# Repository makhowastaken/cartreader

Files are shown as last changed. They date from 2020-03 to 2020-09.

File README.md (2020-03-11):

# cartreader (name pending)

Apologies in advance, this repo is really all over the place. I'm trying to organize and document as I go and it's honestly taken more work to clean this project up and organize it than it has to actually create it in the first place. Things *will* be renamed eventually. 

This device was created from the schematic of [sanni's cart reader](https://github.com/sanni/cartreader) and even uses the same, unmodified firmware. Please see that repo for firmware and firmware updates. This device consists of two parts, the control unit which features the arduino itself, the peripherals, and the power supply, and then the interface adapter, which is largely just a passive adapter to allow you to insert whatever cart. Currently, feature parity has not been reached as I have yet to implement a N64 or Megadrive/Genesis adapter. 

cartreader

## control unit ("sanni_pro")

The Brians of the device. This uses the aftermarket ATMEGA2560 "Pro" boards for a smaller footprint. The actual hardware is largely unchanged from the original Arduino Pros but the footprint is massively reduced. 

This part is designed to be "self contained" and will include all the hardware necessary to operate the device in a portable manner. You need one or more of the following adapters still. 

[Click here for more info, PCB files, and assembly instructions/information of the control unit.](PCB%20Files/control%20unit)

## gb/c and gba adapter ("sanni_gba")

This is the primary adapter that I made this whole module for. I really liked my original reader but I wanted something smaller. This module may actually be combined with any of the other modules by sandwiching the other module inbetween this board and the control unit module.  

[Click here for more info, PCB files, and assembly instructions/information of the GBA adapter.](PCB%20Files/adapters/sanni_gba_shield)

## 8 bit flash module adapter adapter ("sanni_flash")

This is equivalent to the module that plugs into the SNES/SFC slot on sanni's reader that allows you to directly interface with flash chips. It is working (finally) and should interface with the same modules as sanni's version. Only the TSOP48 adapter is tested and confirmed working. I don't have flash chips to test the other adapters. 

[Click here for more info, PCB files, and assembly instructions/information of the flash adapter.](PCB%20Files/adapters/sanni_flash_shield)

## snes / sfc adapter ("sanni_snes")

This adapter is a work in progress. I have uploaded the current version that I have tested and confirmed works (except for the untested CIC lock circuit but it should be fine). Confirmed dumping of SFC games and functionality with sanni's addon modules that interface with the SNES/SFC slot. 

[Click here for more info, PCB files, and assembly instructions/information of the SFC adapter.](PCB%20Files/adapters/sanni_snes_shield)

## n64 adapter

todo

## md/genesis adapter

todo

## other adapters

Sanni's NES/FC adapters, Wonderswan adapter, and SMS adapter should all work through the SNES/SFC adapter but are currently untested.

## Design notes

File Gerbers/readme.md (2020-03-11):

Upload any of these zip files to your favorite PCB fab to get these PCBs made. Oshpark and jlcpcb are good candidates but are by no means the only supported fabs. If you want more info, please check out the [PCB files directory.](./PCB%20Files)

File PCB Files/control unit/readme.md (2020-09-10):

# control unit

Version 1.2c renders

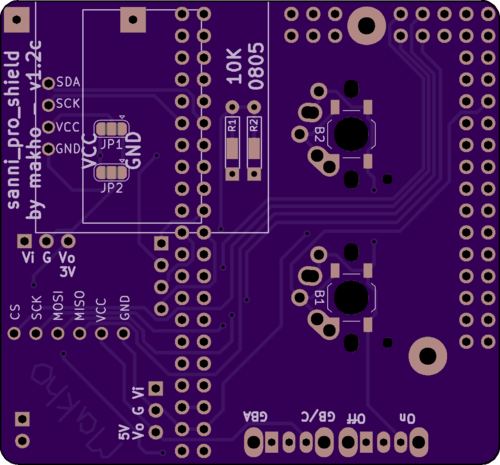
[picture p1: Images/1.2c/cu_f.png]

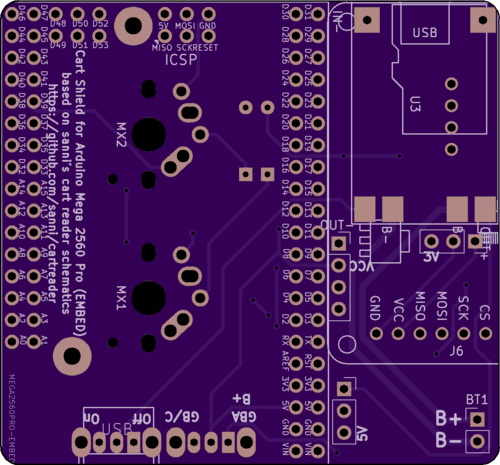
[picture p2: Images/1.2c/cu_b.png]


BOM: 

|Part Desc|Link|Alternative Link|Cost (I used)|Notes|
:--|:--|:--|--:|:--|
|Arduino Mega 2560 Pro (EMBED, NOT MINI)|[https://www.aliexpress.com/item/MEGA-2560-PRO-Embed-CH340G-ATMEGA2560-16AU-Chip-With-Male-Pinheaders-Compatible-for-Arduino-Mega2560-Module/32968779271.html](https://www.aliexpress.com/item/MEGA-2560-PRO-Embed-CH340G-ATMEGA2560-16AU-Chip-With-Male-Pinheaders-Compatible-for-Arduino-Mega2560-Module/32968779271.html)|[https://www.aliexpress.com/item/Mega-2560-PRO-Embed-CH340G-ATmega2560-16AU-with-male-pinheaders-Compatible-for-Arduino-Mega-2560/32801785024.html](https://www.aliexpress.com/item/Mega-2560-PRO-Embed-CH340G-ATmega2560-16AU-with-male-pinheaders-Compatible-for-Arduino-Mega-2560/32801785024.html)|$8.60|I’d recommend the RobotDyn version. I’ve purchased four of these modules so far and two RobotDyn units were fine, one off-brand unit was fine while the other was DOA.|
|2x10K 0805 SMT Resistors|https://www.aliexpress.com/item/100Pcs-0805-SMD-1-4W-0R-10M-chip-resistor-0-10R-100R-220R-330R-470R-1K/32858225842.html| |$0.59|Might as well keep these things handy, they are useful for a lot of DIY type things. The board supports through-hole type resistors as well but I’d recommend the surface-mount ones anyway.|
|2x 4.3mm SMT SPST Push Button (OR mech keyboard switch)|https://novelkeys.xyz/collections/switches/products/novelkeys-x-kailh-low-profile-choc-thick-clicks|[https://www.aliexpress.com/item/2024658734.html](https://www.aliexpress.com/item/2024658734.html)|$2.55|I opted for mech keys that I already had on hand. The board supports Cherry MX (or equivalent), Alps (or equivalent), or Kailh Choc. You can also use 6x6 buttons but you’ll have to fold the legs under the button and solder from the side. Additionally, if you use standard tact switches, you want to make sure that the buttons you use stick out a few MM since it’s a bit of a pain in the rear to use them otherwise.|
|2x THT SPDT Slide Switch|https://www.aliexpress.com/item/50PCS-YT1998Y-SK12D07-Toggle-Switch-3Pin-PCB-2-Position-1P2T-SPDT-Miniature-Slide-Switch-Side-Knob/32827322833.html| |$1.75|You only need two of the 50, but I can’t find any smaller quantities for less. If you’ve already built one of Sanni’s cart reader shields, you probably already have these.|
|RGB LED (Common Anode)|[https://www.aliexpress.com/item/20Pcs-Multicolor-4pin-5mm-RGB-Led-Diode-Light-Lamp-Tricolor-Round-Common-Anode-LED-F5-Light/32852334348.html](https://www.aliexpress.com/item/20Pcs-Multicolor-4pin-5mm-RGB-Led-Diode-Light-Lamp-Tricolor-Round-Common-Anode-LED-F5-Light/32852334348.html)|https://www.ebay.com/itm/291548934125|$0.88|You only need one of the 50. Enjoy finding uses for the other 49. You can also omit this entirely.|
|OLED Screen|[https://www.aliexpress.com/item/0-96-inch-IIC-Serial-White-OLED-Display-Module-128X64-I2C-SSD1306-12864-LCD-Screen-Board/32896971385.html](https://www.aliexpress.com/item/0-96-inch-IIC-Serial-White-OLED-Display-Module-128X64-I2C-SSD1306-12864-LCD-Screen-Board/32896971385.html)| |$2.25|Comes in blue or white. Take your pick. I like the white.|
|TP4056 Charge Module with Low Voltage Protection|https://www.aliexpress.com/item/Free-Shipping-5V-1A-Micro-USB-18650-Lithium-Battery-Charging-Board-Charger-Module-Protection-Dual/32453058256.html| |$0.85|Micro USB variant is cheaper but this is your charge port and you can use Mini USB or USB C if you like. As long as you get the protected version, the footprint should match.|
|702540 Cell|[https://www.aliexpress.com/item/32878325857.html](https://www.aliexpress.com/item/32878325857.html)| |$8.00|Any “Game Boy Micro” sized battery should fit perfectly within the space between the actual cart interface shield and the arduino. If you have something laying around, that’s even better as this is the second most expensive part of the build (well, third depending on the PCBs)|
|5v 0.45A Voltage Regulator|[https://www.aliexpress.com/item/32786144773.html](https://www.aliexpress.com/item/32786144773.html)| |$1.54|A regulator that can handle more current would be better but this one is well within spec for Game Boy Games. SNES will require supplementary hardware. Any other three pin regulator should work, just mind that the PCB is expecting the middle pin to be ground.|
|3.3v 0.59A Voltage Regulator|[https://www.aliexpress.com/item/32914681832.html](https://www.aliexpress.com/item/32914681832.html)| |$1.47|Any three pin regulator should work, just mind that the middle pin is ground|
|Micro SD Module|[https://www.aliexpress.com/item/1PCS-Micro-SD-Storage-Expansion-Board-Mciro-SD-TF-Card-Memory-Shield-Module-SPI-For-Arduino/32523546123.html](https://www.aliexpress.com/item/1PCS-Micro-SD-Storage-Expansion-Board-Mciro-SD-TF-Card-Memory-Shield-Module-SPI-For-Arduino/32523546123.html)| |$1.04|This hardware does not support the full size SD Module (but only because I did not include the pins -- electrically, it should work fine).|
|Battery gauge (volt meter panel)|[https://www.aliexpress.com/item/32851937196.html](https://www.aliexpress.com/item/32851937196.html)| |$0.85|This is completely optional, but I like it. I also designed the PCB with this in mind so there will be an empty spot if you omit it.|
||||||
|2.54 MM Headers||||You only need the sockets if you think you might want to take this apart at some point. The sockets are required if you want to do more than rip whatever shield you assemble this with. XL pins are recommended for socket-less builds (not tested or linked).|
| Pins|https://www.aliexpress.com/item/10PCS-40Pin-1x40P-Male-Breakable-Pin-Header-Strip-2-54mm-Long-Blue-Red-White-Green-Yellow/32863408765.html| |$0.55|I had a ton of these laying around. With the pins, you can just break off however many you need and solder those on. You can also double-stack them pretty easily for things like the Arduino. The Arduino probably already came with pins though.|
| Sockets|[https://www.aliexpress.com/item/32889916876.html](https://www.aliexpress.com/item/32889916876.html)| |$4.32|You’ll need to get the 2x3, 2x16, and 2x20 option to socket the Arduino. I do not recommend socketing any other components on this model.|
|Total|||$36.79|Prices may have changed on somethings or shipping may be more or less expensive to your area.|

Please let me know if any parts go out of stock or if the listing disappears so that I can add an alternative. 

Assembly must be completed in order. Due to the close proximity of the parts, flush cutters are required and kapton tape for insulation is *highly* recommended. [Please see my video for an example of assembly.](https://youtu.be/GbIMFZ5j5U0)

---

New v1.3???

I have updated the PCB to use [my soft latching power button circuit](https://github.com/makhowastaken/Soft-Latching-Power-Button) and have otherwise slightly tweaked the traces to look better using oshpark's after dark fab process. Like previous boards, this is functionally identical and the only new feature is a momentary push button (swap one of the SPDT switches for the BOM listed in the above linked repo). Going forward, this is likely the board I will be updating but since I have not changed any critical dimensions, not much should change. 

This revision should work since all I did was combine two tested, working designs but since I have yet to actually assemble one, it should be considered untested. 

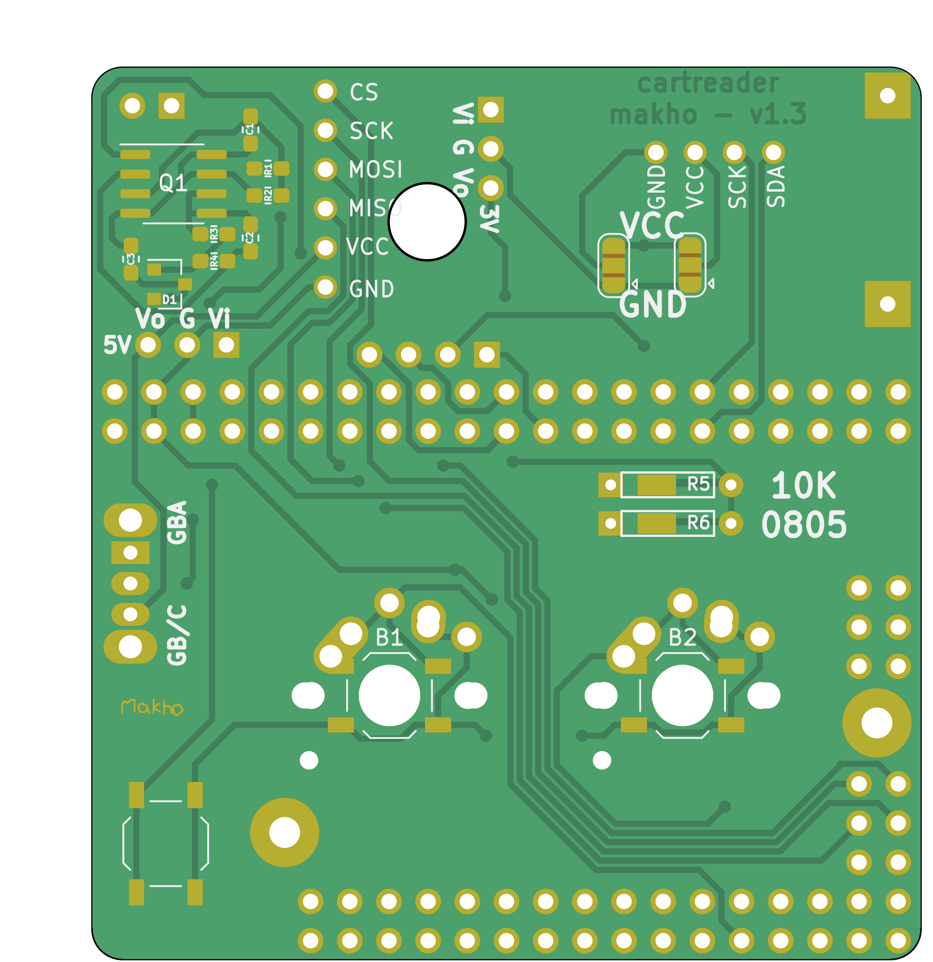
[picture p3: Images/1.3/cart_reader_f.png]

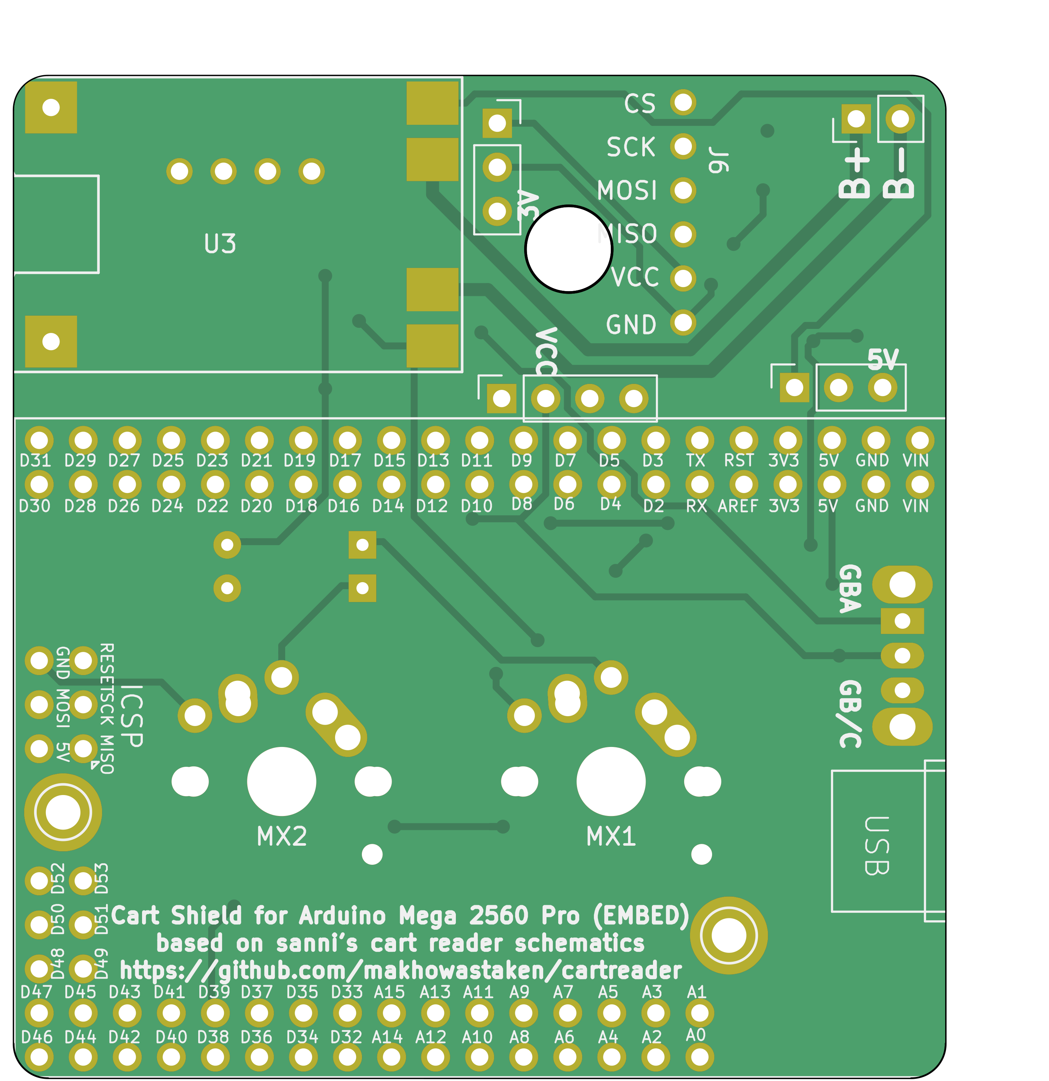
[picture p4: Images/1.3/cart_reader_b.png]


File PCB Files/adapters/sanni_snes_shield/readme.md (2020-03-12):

# snes / sfc adapter

Version 1.2c renders

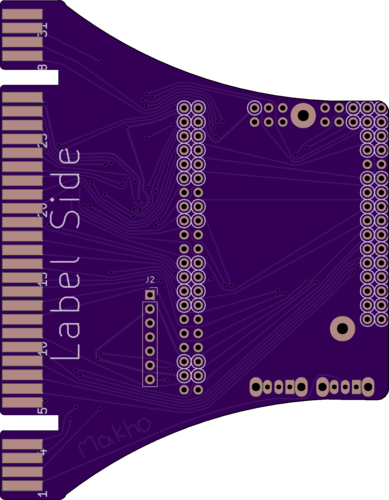
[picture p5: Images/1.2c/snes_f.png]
front

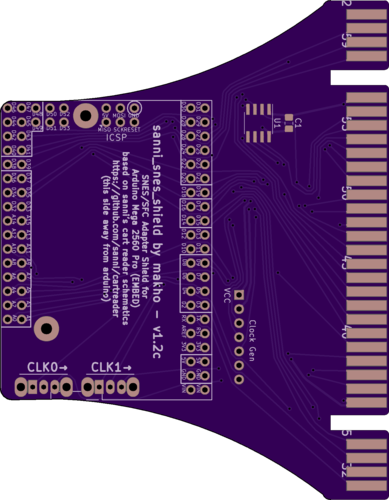
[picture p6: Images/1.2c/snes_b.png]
back


this is a work in progress. This is currently tested and confirmed working but some things are in dumb spots. I kinda just winged this whole thing.

BOM:
(todo)
The cart slot, CIC lock hardware, clock signal generator, two more of the SPDT switches that you used for the control unit, and probably something else that I'm forgetting.

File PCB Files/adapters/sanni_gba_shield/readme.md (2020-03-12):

# game boy game pak adapter

Version 1.2c renders

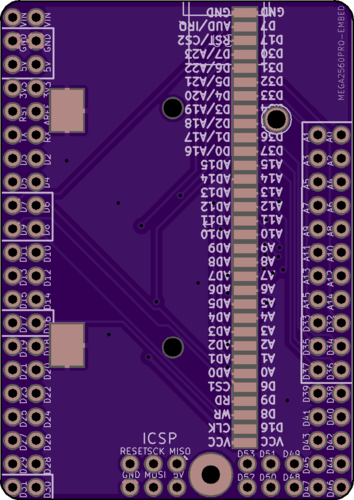
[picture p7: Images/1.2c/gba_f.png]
front

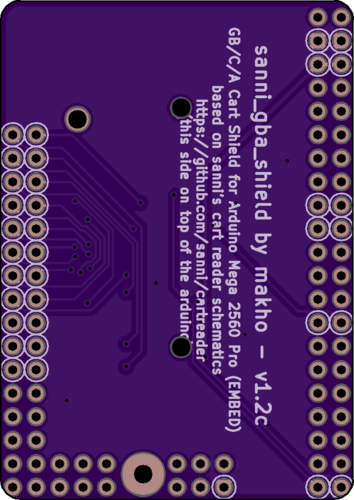
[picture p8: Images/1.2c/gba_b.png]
back


BOM:

[the cart slot](https://www.aliexpress.com/item/For-Nintendo-DS-NDSL-GBA-Game-Cartridge-Card-Reader-Slot-Repair-Part/32679592016.html) and then some header pins (you can use the ones that came with the arduino)

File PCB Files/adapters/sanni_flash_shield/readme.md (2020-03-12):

# 8 bit flash adapter

Version 1.2c renders

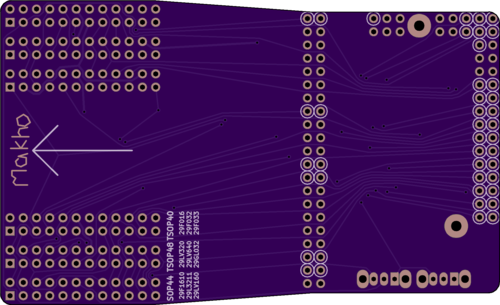
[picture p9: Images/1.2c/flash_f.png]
front

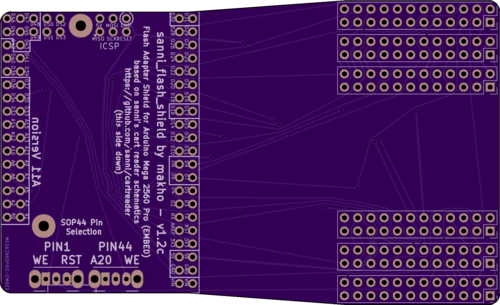
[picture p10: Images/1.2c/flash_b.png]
back


BOM:
(todo)
lots of pin headers, two more SPDT switches that you used to build the control unit (only required for the SOP adapter), and then the adapters themselves. 

[assembly video here (soon)](https://youtu.be/Xz5Vwh5hB-U)

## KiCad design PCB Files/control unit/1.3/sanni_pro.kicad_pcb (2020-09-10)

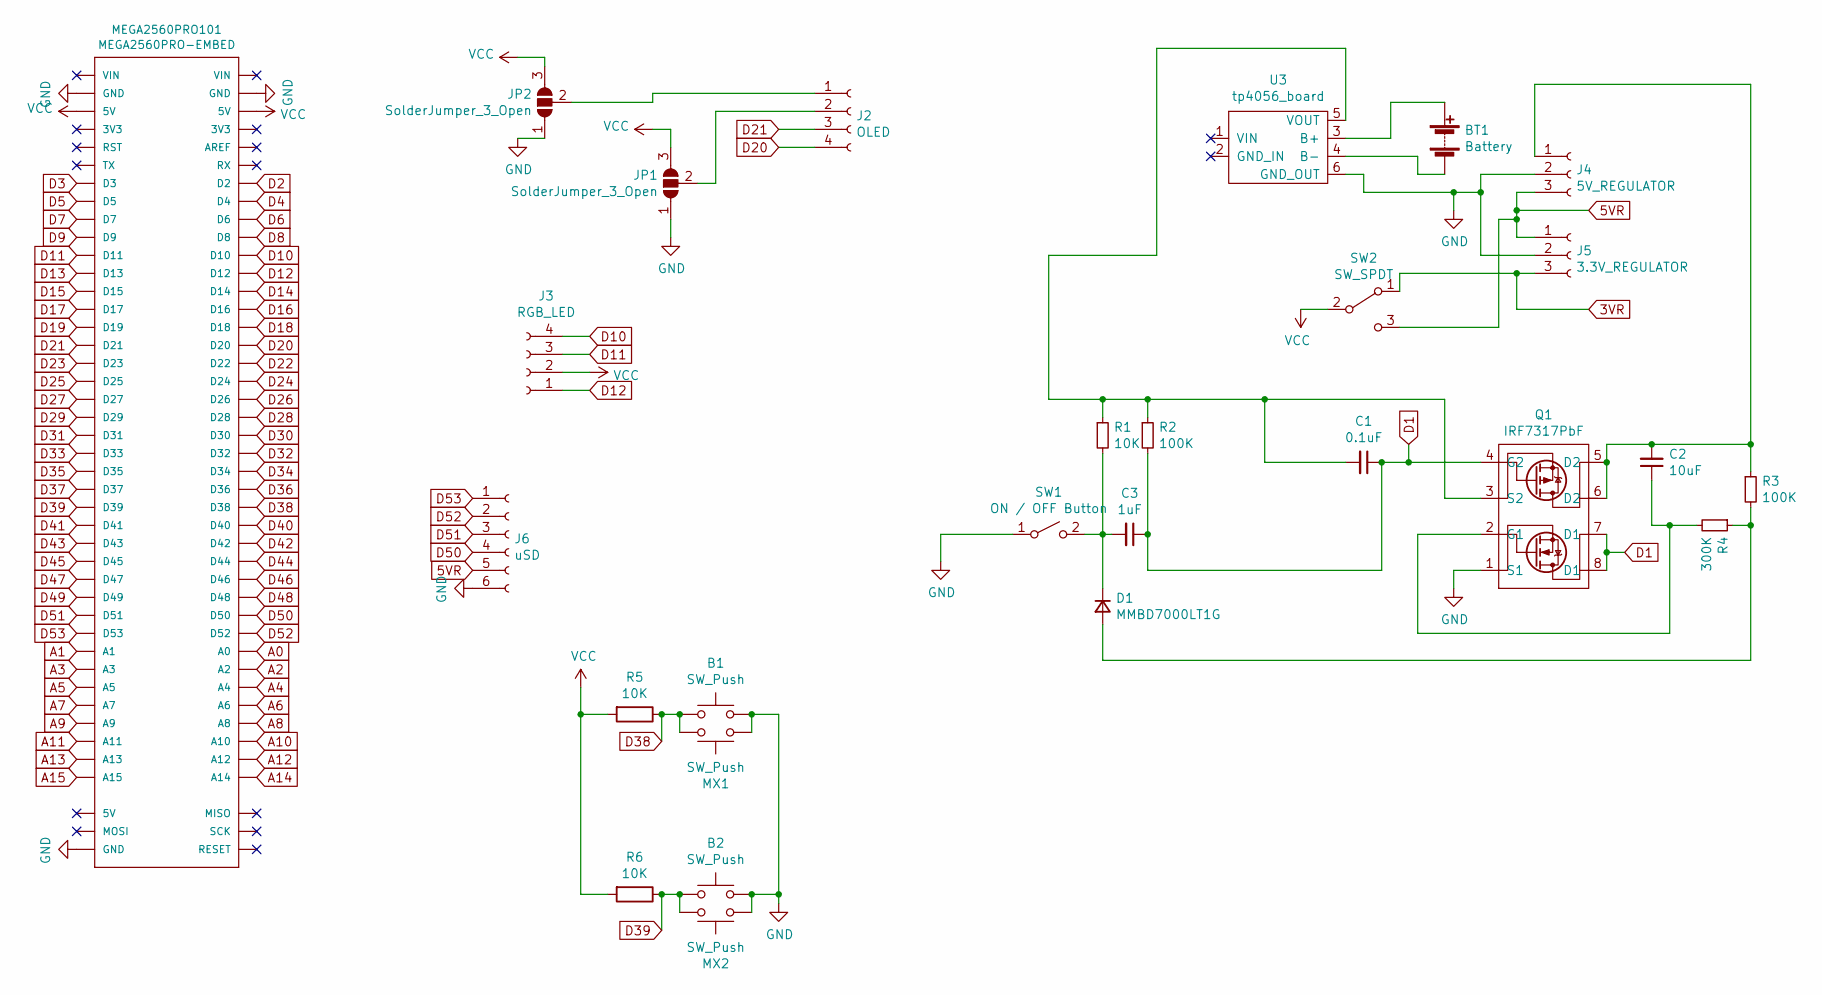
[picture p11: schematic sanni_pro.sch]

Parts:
B1, B2: SW_Push; SW_SPST_TL3342
BT1: Battery; PinHeader_1x02_P2.54mm_Vertical
C1: 0.1uF; C_0603_1608Metric_Pad1.05x0.95mm_HandSolder
C2: 10uF; C_0603_1608Metric_Pad1.05x0.95mm_HandSolder
C3: 1uF; C_0603_1608Metric_Pad1.05x0.95mm_HandSolder
D1: MMBD7000LT1G; D_SOT-23_ANK
J2: OLED; OLED_Module
J3: RGB_LED; PinSocket_1x04_P2.54mm_Vertical
J4: 5V_REGULATOR; PinSocket_1x03_P2.54mm_Vertical
J5: 3.3V_REGULATOR; PinSocket_1x03_P2.54mm_Vertical
J6: uSD; Catalex_uSD_BSilk
JP1, JP2: SolderJumper_3_Open; SolderJumper-3_P1.3mm_Open_RoundedPad1.0x1.5mm
MEGA2560PRO101: MEGA2560PRO-EMBED
MX1, MX2: SW_Push; MX-Alps-Choc-1U-NoLED_fixed
Q1: IRF7317PbF; SOIC-8_3.9x4.9mm_P1.27mm
R1: 10K; R_0603_1608Metric_Pad1.05x0.95mm_HandSolder
R2, R3: 100K; R_0603_1608Metric_Pad1.05x0.95mm_HandSolder
R4: 300K; R_0603_1608Metric_Pad1.05x0.95mm_HandSolder
R5, R6: 10K; Resistor-hybrid-3pad
SW1: ON / OFF Button; SW_SPST_TL3342
SW2: SW_SPDT; SW_CuK_OS102011MA1QN1_SPDT_Angled
U3: tp4056_board; 4056E_LiIon_loader_SMT

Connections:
3VR: J5.3, SW2.1 (A)
5VR: J4.3, J5.1, J6.5, SW2.3 (C)
A0: MEGA2560PRO101.A0
A1: MEGA2560PRO101.A1
A2: MEGA2560PRO101.A2
A3: MEGA2560PRO101.A3
A4: MEGA2560PRO101.A4
A5: MEGA2560PRO101.A5
A6: MEGA2560PRO101.A6
A7: MEGA2560PRO101.A7
A8: MEGA2560PRO101.A8
A9: MEGA2560PRO101.A9
A10: MEGA2560PRO101.A10
A11: MEGA2560PRO101.A11
A12: MEGA2560PRO101.A12
A13: MEGA2560PRO101.A13
A14: MEGA2560PRO101.A14
A15: MEGA2560PRO101.A15
D1: C1.1, C3.1, Q1.4 (G2), Q1.7 (D1), Q1.8 (D1), R2.2
D2: MEGA2560PRO101.D2
D3: MEGA2560PRO101.D3
D4: MEGA2560PRO101.D4
D5: MEGA2560PRO101.D5
D6: MEGA2560PRO101.D6
D7: MEGA2560PRO101.D7
D8: MEGA2560PRO101.D8
D9: MEGA2560PRO101.D9
D10: J3.4, MEGA2560PRO101.D10
D11: J3.3, MEGA2560PRO101.D11
D12: J3.1, MEGA2560PRO101.D12
D13: MEGA2560PRO101.D13
D14: MEGA2560PRO101.D14
D15: MEGA2560PRO101.D15
D16: MEGA2560PRO101.D16
D17: MEGA2560PRO101.D17
D18: MEGA2560PRO101.D18
D19: MEGA2560PRO101.D19
D20: J2.4, MEGA2560PRO101.D20
D21: J2.3, MEGA2560PRO101.D21
D22: MEGA2560PRO101.D22
D23: MEGA2560PRO101.D23
D24: MEGA2560PRO101.D24
D25: MEGA2560PRO101.D25
D26: MEGA2560PRO101.D26
D27: MEGA2560PRO101.D27
D28: MEGA2560PRO101.D28
D29: MEGA2560PRO101.D29
D30: MEGA2560PRO101.D30
D31: MEGA2560PRO101.D31
D32: MEGA2560PRO101.D32
D33: MEGA2560PRO101.D33
D34: MEGA2560PRO101.D34
D35: MEGA2560PRO101.D35
D36: MEGA2560PRO101.D36
D37: MEGA2560PRO101.D37
D38: B1.1, MEGA2560PRO101.D38, MX1.2, R5.1
D39: B2.1, MEGA2560PRO101.D39, MX2.2, R6.1
D40: MEGA2560PRO101.D40
D41: MEGA2560PRO101.D41
D42: MEGA2560PRO101.D42
D43: MEGA2560PRO101.D43
D44: MEGA2560PRO101.D44
D45: MEGA2560PRO101.D45
D46: MEGA2560PRO101.D46
D47: MEGA2560PRO101.D47
D48: MEGA2560PRO101.D48
D49: MEGA2560PRO101.D49
D50: J6.4, MEGA2560PRO101.D50
D51: J6.3, MEGA2560PRO101.D51
D52: J6.2, MEGA2560PRO101.D52
D53: J6.1, MEGA2560PRO101.D53
GND: B1.2, B2.2, J4.2, J5.2, J6.6, JP1.1 (A), JP2.1 (A), MEGA2560PRO101.GND@1 (GND), MEGA2560PRO101.GND@2 (GND), MEGA2560PRO101.GND@3 (GND), MX1.1, MX2.1, Q1.1 (S1), SW1.1 (A), U3.6 (GND_OUT)
unnamed: BT1.1 (+), U3.3 (B+)
unnamed: BT1.2 (-), U3.4 (B-)
unnamed: C2.1, Q1.2 (G1), R4.2
unnamed: C3.2, D1.1 (K), R1.2, SW1.2 (B)
unnamed: D1.2 (A), R3.2, R4.1
unnamed: J2.1, JP2.2 (C)
unnamed: J2.2, JP1.2 (C)
VCC: J3.2, JP1.3 (B), JP2.3 (B), MEGA2560PRO101.5V@1 (5V), MEGA2560PRO101.5V@2 (5V), R5.2, R6.2, SW2.2 (B)

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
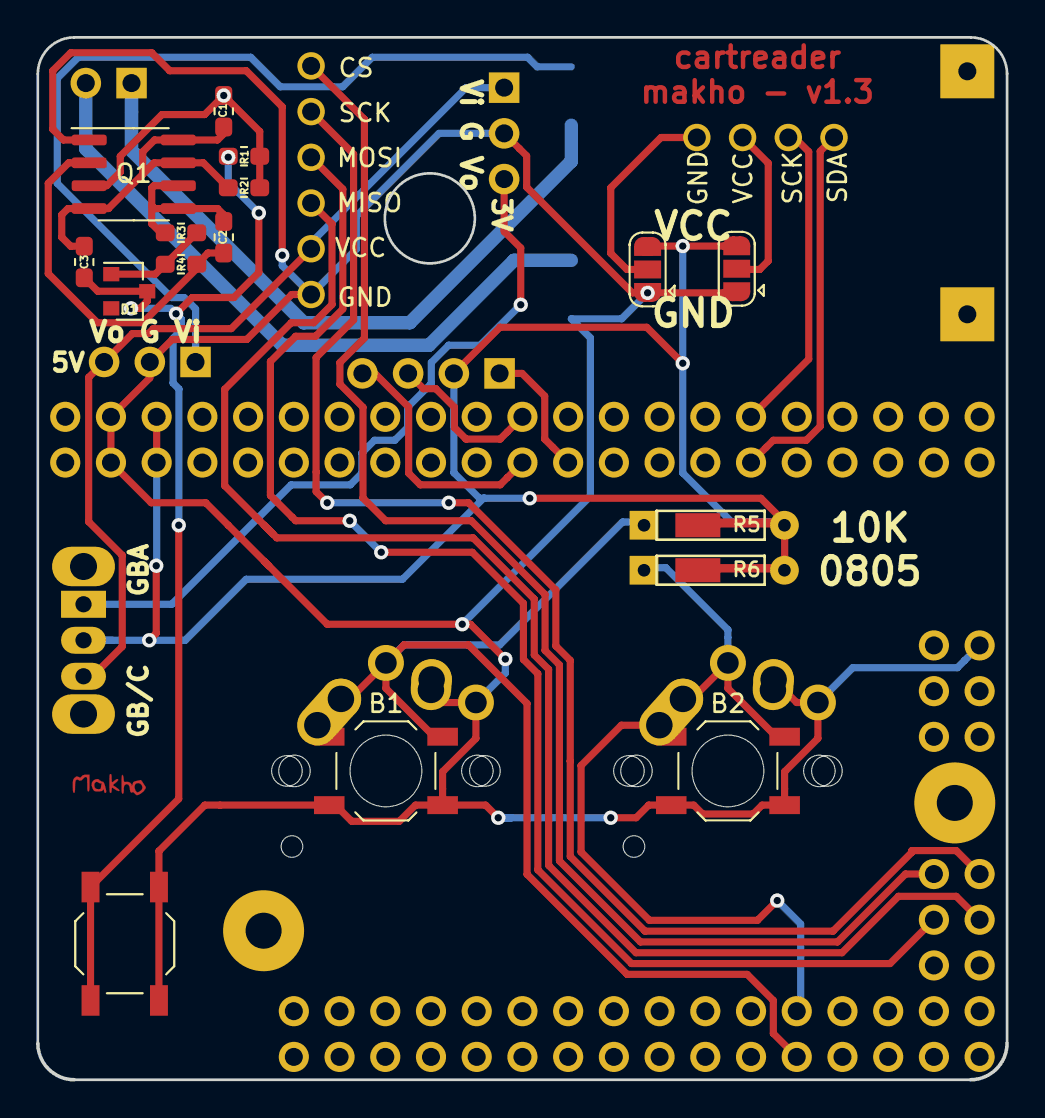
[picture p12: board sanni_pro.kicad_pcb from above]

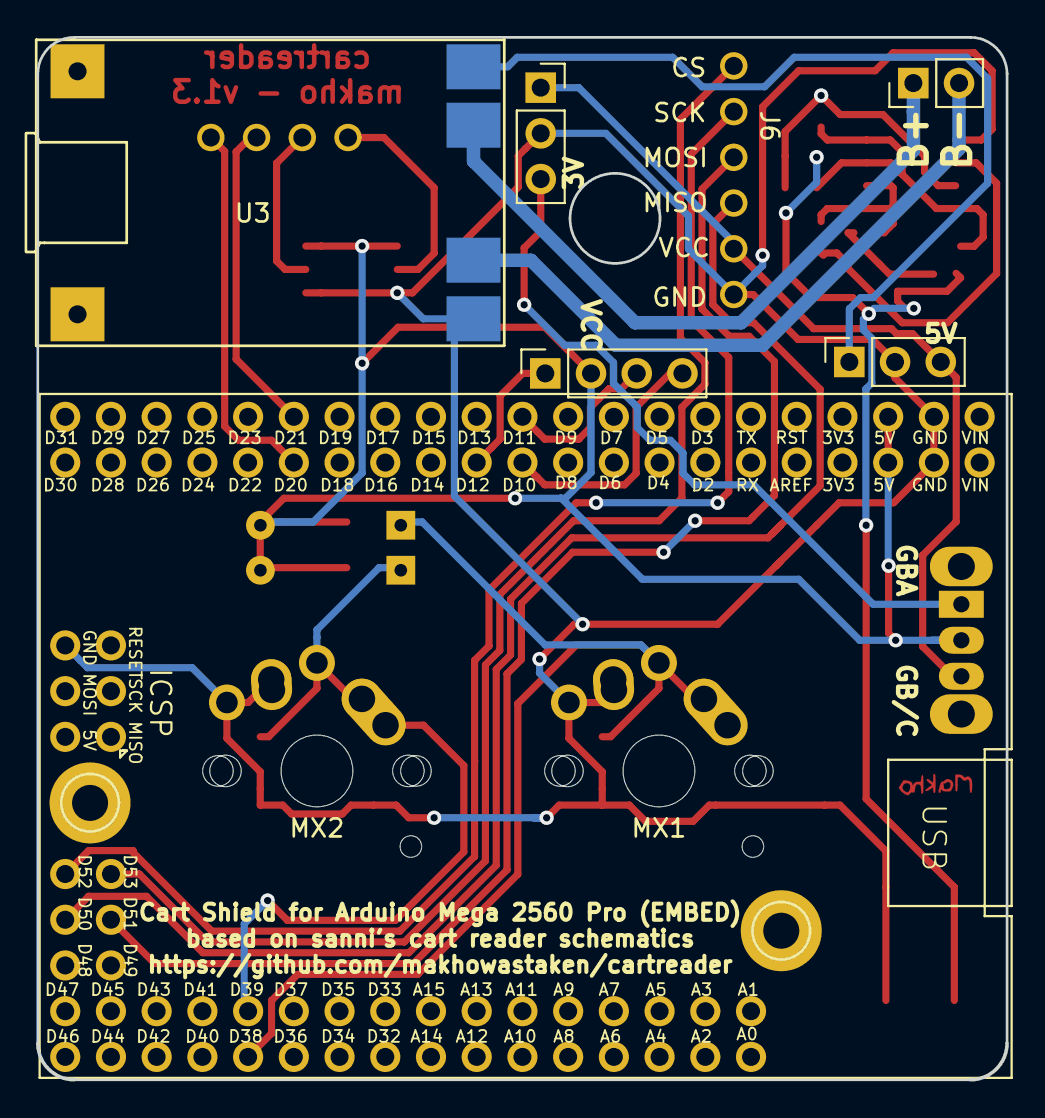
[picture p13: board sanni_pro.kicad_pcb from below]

Board: 2 copper layers, 53.8 x 57.9 mm, 28 parts (6 on the bottom side), 25 nets.

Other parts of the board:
Ref**: Val**; makho_micro_fmask

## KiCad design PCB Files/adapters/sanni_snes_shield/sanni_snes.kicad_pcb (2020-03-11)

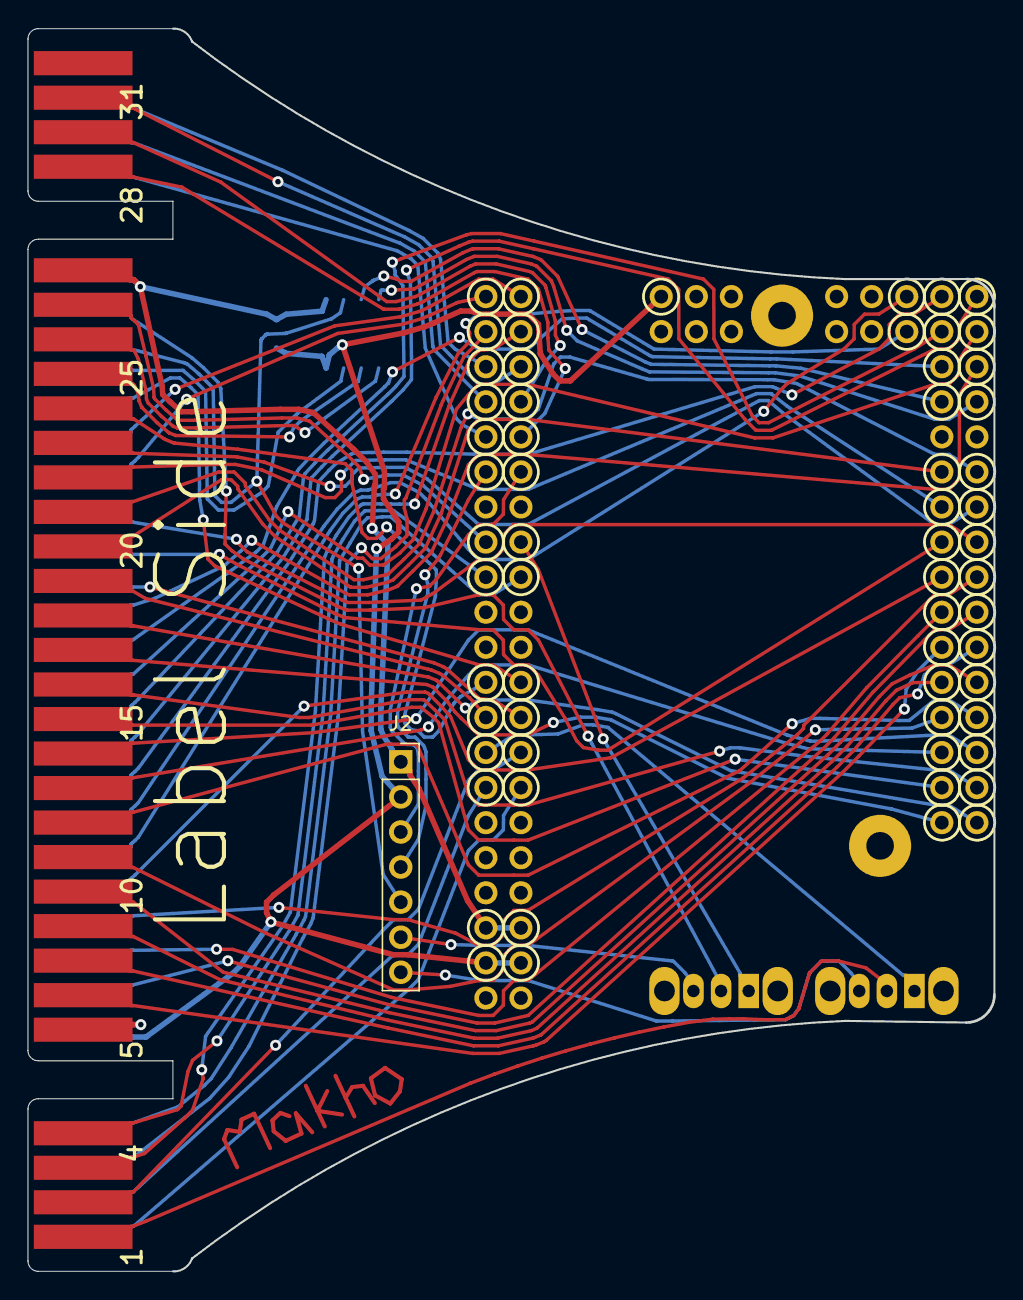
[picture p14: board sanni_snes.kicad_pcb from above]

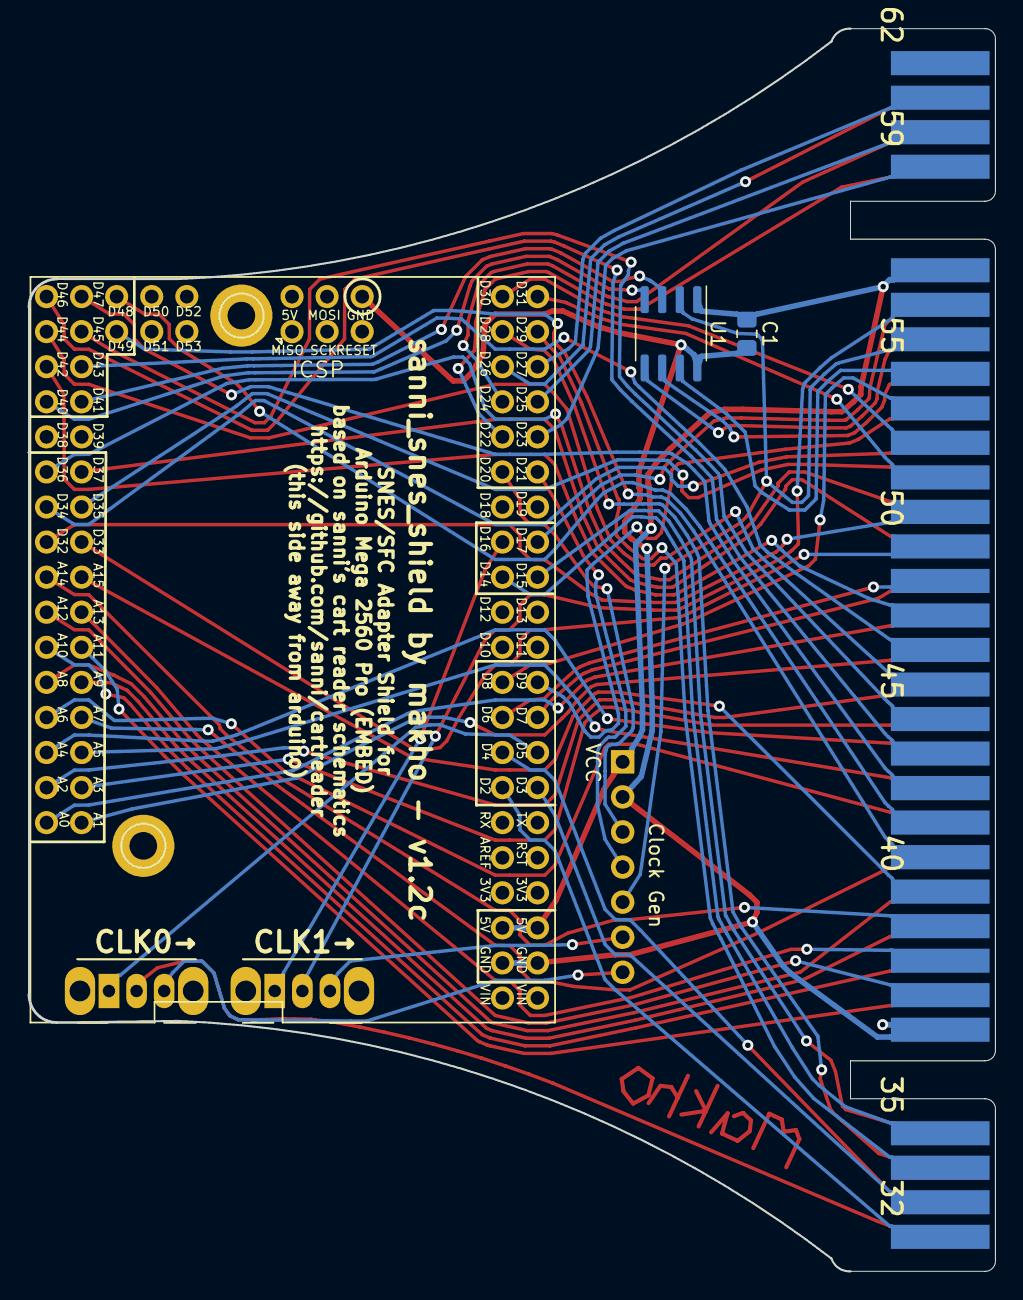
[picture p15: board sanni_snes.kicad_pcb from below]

Board: 2 copper layers, 70.0 x 90.0 mm, 7 parts (5 on the bottom side), 66 nets.

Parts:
C1: 100nF; C_0805_2012Metric_Pad1.15x1.40mm_HandSolder
J1: SNES_EXP_CONN; SNES-CART-EXP-EDGE-CONN
J2: CLOCKGEN; PinSocket_1x07_P2.54mm_Vertical
MEGA2560PRO101: MEGA2560PRO-EMBED
SW1: CLK0; SW_CuK_OS102011MA1QN1_SPDT_Angled
SW2: CLK1; SW_CuK_OS102011MA1QN1_SPDT_Angled
U1: PIC12F629-ISN; SOIC-8_3.9x4.9mm_P1.27mm

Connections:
A0: J1.17, MEGA2560PRO101.A0
A1: J1.16, MEGA2560PRO101.A1
A2: J1.15, MEGA2560PRO101.A2
A3: J1.14, MEGA2560PRO101.A3
A4: J1.13, MEGA2560PRO101.A4
A5: J1.12, MEGA2560PRO101.A5
A6: J1.11, MEGA2560PRO101.A6
A7: J1.10, MEGA2560PRO101.A7
A8: J1.9, MEGA2560PRO101.A8
A9: J1.8, MEGA2560PRO101.A9
A10: J1.7, MEGA2560PRO101.A10
A11: J1.6, MEGA2560PRO101.A11
A12: J1.37, MEGA2560PRO101.A12
A13: J1.38, MEGA2560PRO101.A13
A14: J1.39, MEGA2560PRO101.A14
A15: J1.40, MEGA2560PRO101.A15
CIC0: J1.55, U1.7
CIC1: J1.24, U1.6
CICCLK: J1.56, J2.5, U1.2
CLK0: J2.7, SW1.3
CLK1: J2.6, SW2.3
D2: J1.32, MEGA2560PRO101.D2
D3: J1.33, MEGA2560PRO101.D3
D4: J1.2, MEGA2560PRO101.D4
D5: MEGA2560PRO101.D5, SW1.1
D6: J1.49, MEGA2560PRO101.D6
D7: J1.18, MEGA2560PRO101.D7
D8: J1.54, MEGA2560PRO101.D8
D9: J1.23, MEGA2560PRO101.D9
D14: J1.35, MEGA2560PRO101.D14
D15: J1.4, MEGA2560PRO101.D15
D16: MEGA2560PRO101.D16, SW2.1
D17: J1.26, MEGA2560PRO101.D17
D20: J2.3, MEGA2560PRO101.D20
D21: J2.4, MEGA2560PRO101.D21
D22: J1.28, MEGA2560PRO101.D22
D23: J1.59, MEGA2560PRO101.D23
D24: J1.29, MEGA2560PRO101.D24
D25: J1.60, MEGA2560PRO101.D25
D26: J1.30, MEGA2560PRO101.D26
D27: J1.61, MEGA2560PRO101.D27
D28: J1.3, MEGA2560PRO101.D28
D29: J1.34, MEGA2560PRO101.D29
D30: J1.53, MEGA2560PRO101.D30
D31: J1.52, MEGA2560PRO101.D31
D32: J1.51, MEGA2560PRO101.D32
D33: J1.50, MEGA2560PRO101.D33
D34: J1.22, MEGA2560PRO101.D34
D35: J1.21, MEGA2560PRO101.D35
D36: J1.20, MEGA2560PRO101.D36
D37: J1.19, MEGA2560PRO101.D37
D40: MEGA2560PRO101.D40, U1.4
D41: MEGA2560PRO101.D41, U1.3
D42: J1.48, MEGA2560PRO101.D42
D43: J1.47, MEGA2560PRO101.D43
D44: J1.46, MEGA2560PRO101.D44
D45: J1.45, MEGA2560PRO101.D45
D46: J1.44, MEGA2560PRO101.D46
D47: J1.43, MEGA2560PRO101.D47
D48: J1.42, MEGA2560PRO101.D48
D49: J1.41, MEGA2560PRO101.D49
GND: C1.2, J1.5, J1.36, J2.2, MEGA2560PRO101.GND@1, MEGA2560PRO101.GND@2, MEGA2560PRO101.GND@3, U1.8
Reset_In: J1.25, U1.5
SW1CLK: J1.1, SW1.2
SW2CLK: J1.57, SW2.2
VCC: C1.1, J1.27, J1.58, J2.1, MEGA2560PRO101.5V@1, MEGA2560PRO101.5V@2, U1.1

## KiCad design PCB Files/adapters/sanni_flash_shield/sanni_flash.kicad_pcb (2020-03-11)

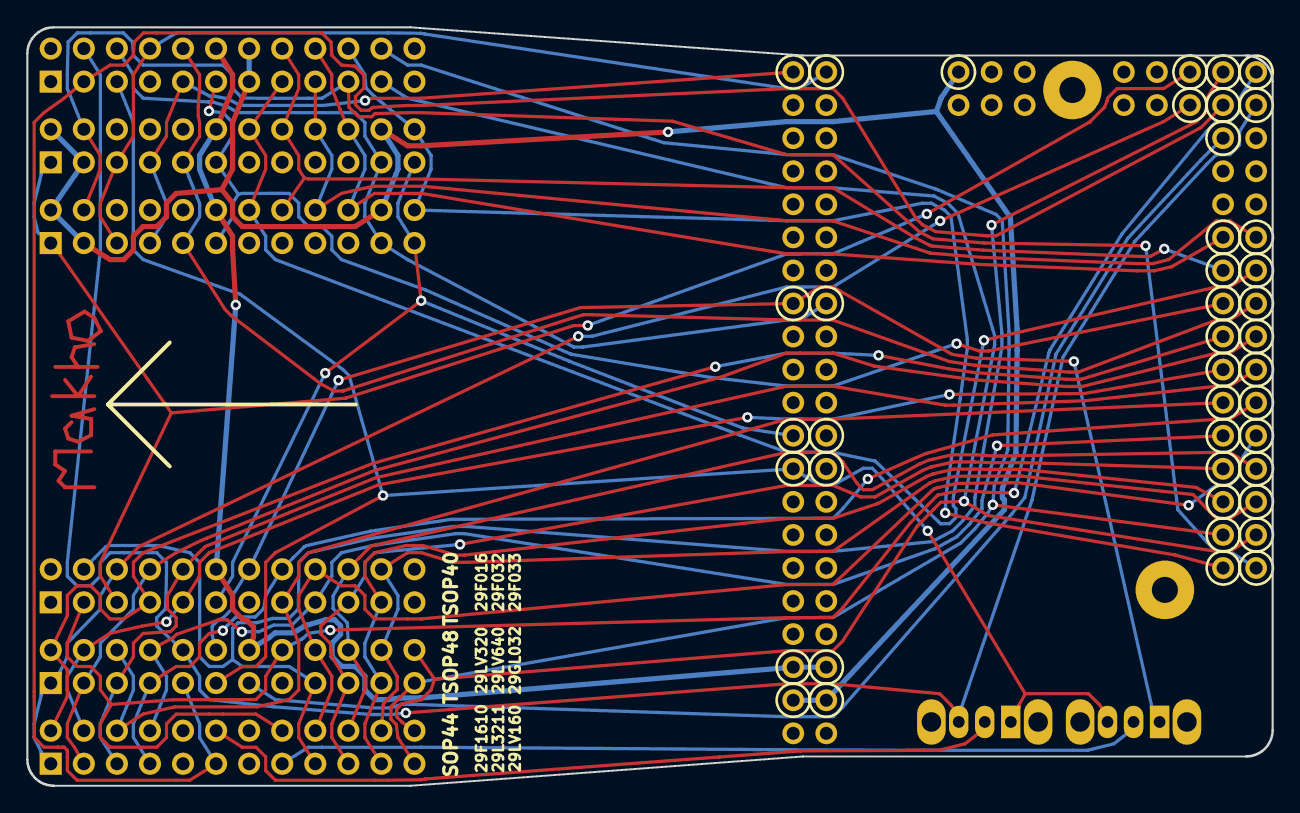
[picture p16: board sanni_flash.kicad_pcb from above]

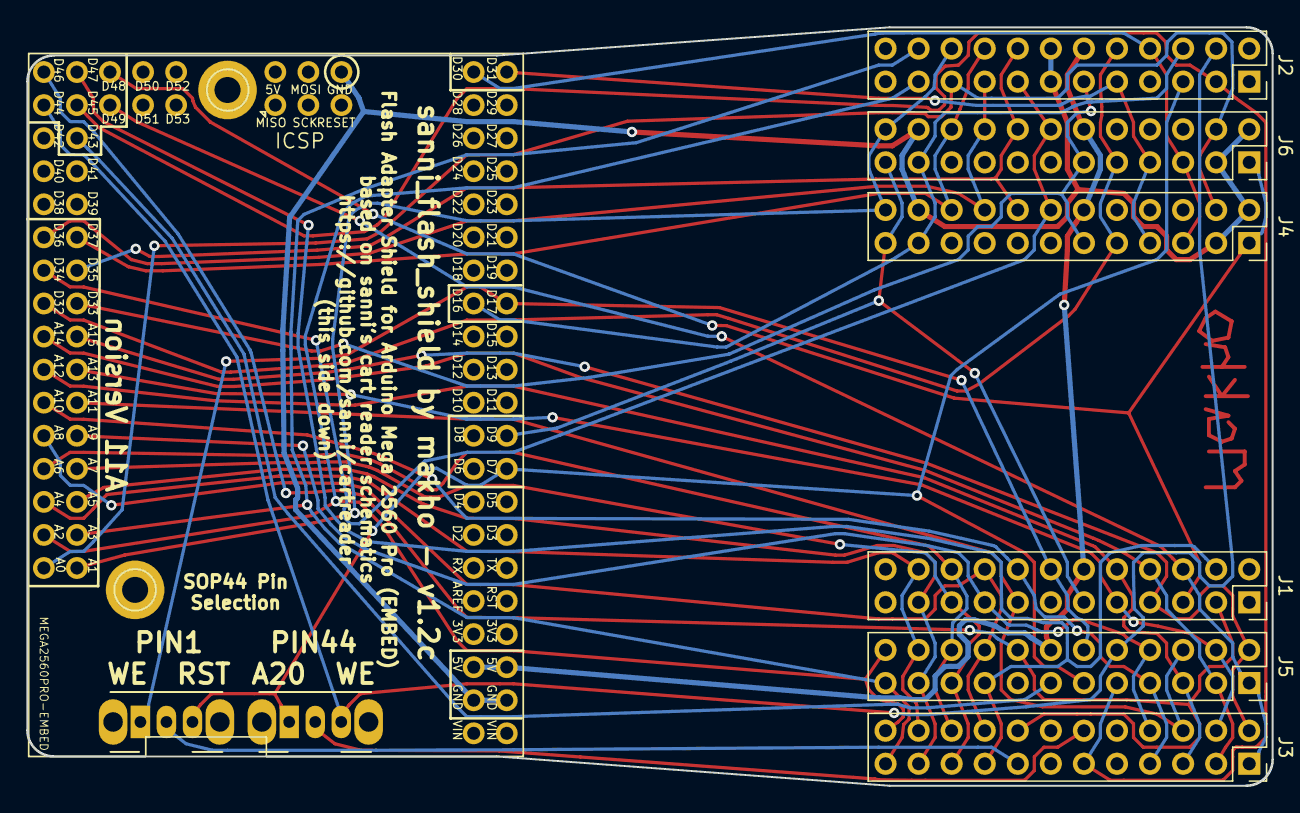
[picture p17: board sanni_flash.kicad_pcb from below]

Board: 2 copper layers, 95.7 x 58.3 mm, 9 parts (9 on the bottom side), 39 nets.

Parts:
J1: TSOP40_L; PinSocket_2x12_P2.54mm_Vertical
J2: TSOP40_R; PinSocket_2x12_P2.54mm_Vertical
J3: SOP44_L; PinSocket_2x12_P2.54mm_Vertical
J4: SOP44_R; PinSocket_2x12_P2.54mm_Vertical
J5: TSOP48_L; PinSocket_2x12_P2.54mm_Vertical
J6: TSOP48_R; PinSocket_2x12_P2.54mm_Vertical
MEGA2560PRO101: MEGA2560PRO-EMBED
SW1: A20/WE (SOP44); SW_CuK_OS102011MA1QN1_SPDT_Angled
SW2: WE/RST (SOP44); SW_CuK_OS102011MA1QN1_SPDT_Angled

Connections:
A0: J2.19, J4.4, J6.4, MEGA2560PRO101.A0
A1: J2.20, J4.24, J6.24, MEGA2560PRO101.A1
A2: J2.21, J3.24, J5.24, MEGA2560PRO101.A2
A3: J2.22, J3.23, J5.23, MEGA2560PRO101.A3
A4: J1.22, J3.22, J5.22, MEGA2560PRO101.A4
A5: J1.21, J3.21, J5.21, MEGA2560PRO101.A5
A6: J1.20, J3.20, J5.20, MEGA2560PRO101.A6
A7: J1.19, J3.19, J5.19, MEGA2560PRO101.A7
A8: J1.18, J3.18, J5.18, MEGA2560PRO101.A8
A9: J1.17, J3.8, J5.8, MEGA2560PRO101.A9
A10: J1.16, J3.7, J5.7, MEGA2560PRO101.A10
A11: J1.15, J3.6, J5.6, MEGA2560PRO101.A11
A12: J1.10, J3.5, J5.5, MEGA2560PRO101.A12
A13: J1.9, J3.4, J5.4, MEGA2560PRO101.A13
A14: J1.8, J3.3, J5.3, MEGA2560PRO101.A14
A15: J1.7, J3.2, J5.2, MEGA2560PRO101.A15
A20WE: J3.12, SW1.2
D7: J2.5, J5.11, MEGA2560PRO101.D7, SW1.1, SW2.3
D9: J1.11, J4.23, J6.23, MEGA2560PRO101.D9
D16: J2.6, J4.21, J6.21, MEGA2560PRO101.D16
D17: J1.14, J5.12, MEGA2560PRO101.D17, SW2.1
D30: J2.8, J4.5, J6.5, MEGA2560PRO101.D30
D31: J2.9, J4.7, J6.7, MEGA2560PRO101.D31
D32: J2.10, J4.9, J6.9, MEGA2560PRO101.D32
D33: J2.11, J4.11, J6.11, MEGA2560PRO101.D33
D34: J2.15, J4.14, J6.14, MEGA2560PRO101.D34
D35: J2.16, J4.16, J6.16, MEGA2560PRO101.D35
D36: J2.17, J4.18, J6.18, MEGA2560PRO101.D36
D37: J2.18, J4.20, J6.20, MEGA2560PRO101.D37
D43: J5.13, MEGA2560PRO101.D43
D44: J2.4, J5.10, MEGA2560PRO101.D44, SW1.3
D45: J2.3, J3.11, J5.9, MEGA2560PRO101.D45
D46: J1.3, J3.16, J5.16, MEGA2560PRO101.D46
D47: J1.4, J3.17, J5.17, MEGA2560PRO101.D47
D48: J1.5, J4.1, J6.1, MEGA2560PRO101.D48
D49: J1.6, J3.1, J5.1, MEGA2560PRO101.D49
GND: J2.13, J2.14, J4.2, J4.3, J4.22, J6.2, J6.3, J6.22, MEGA2560PRO101.GND@1, MEGA2560PRO101.GND@2, MEGA2560PRO101.GND@3
VCC: J1.12, J2.12, J4.12, J5.14, J6.12, MEGA2560PRO101.5V@1, MEGA2560PRO101.5V@2
WERST: J3.15, SW2.2

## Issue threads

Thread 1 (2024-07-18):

Missing solder mask on sanni pro v1.3

coolikot, 2024-07-18:
Hello I tried sending the gerbers file to PCBway but it seems the 1.3 revision is missing a solder mask.

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

Also some links to parts are not available anymore:
-2x 4.3mm SMT SPST Push Button (OR mech keyboard switch) | https://novelkeys.xyz/collections/switches/products/novelkeys-x-kailh-low-profile-choc-thick-clicks
-3.3v 0.59A Voltage Regulator | https://www.aliexpress.com/item/32914681832.html
-Battery gauge (volt meter panel) | https://www.aliexpress.com/item/32851937196.html

makhowastaken, 2025-02-14:
fixed the gerber file, my bad

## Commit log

2020-04-23 Update readme.md
    fixed broken switch link
2020-09-10 made folder organization more consistent
    [Momentary-Power-Toggle.sch, sanni_pro.kicad_pcb, sanni_pro.sch]
